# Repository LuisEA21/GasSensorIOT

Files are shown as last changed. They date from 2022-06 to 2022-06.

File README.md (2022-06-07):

# GasSensorIoT

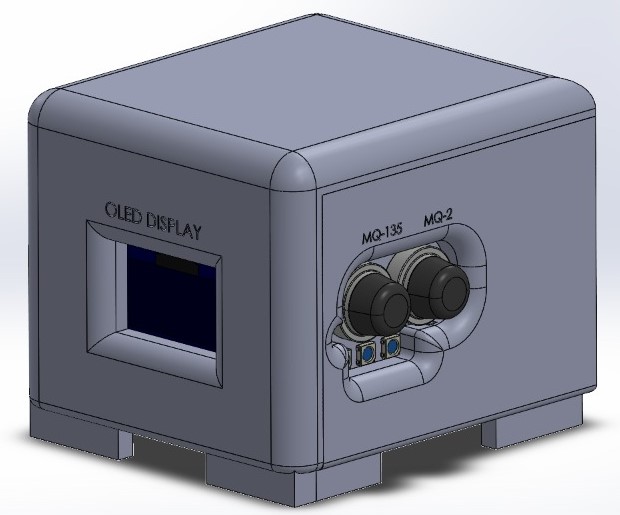
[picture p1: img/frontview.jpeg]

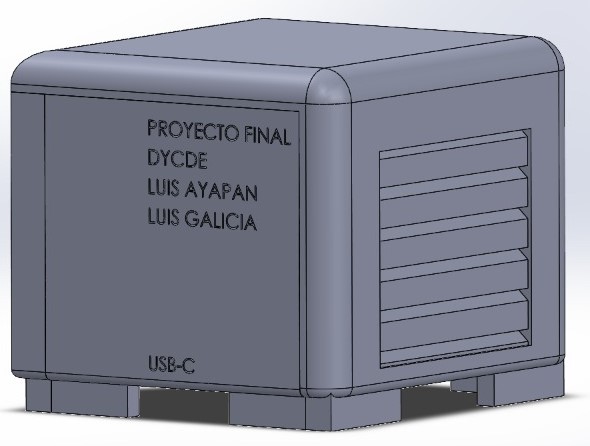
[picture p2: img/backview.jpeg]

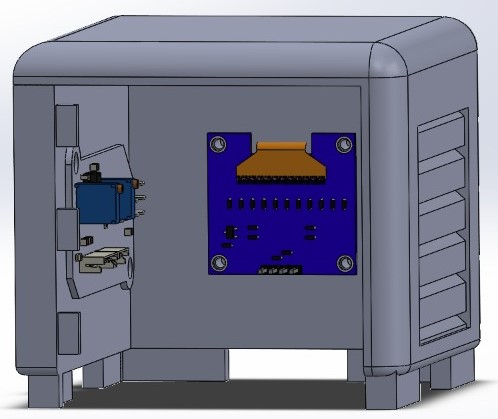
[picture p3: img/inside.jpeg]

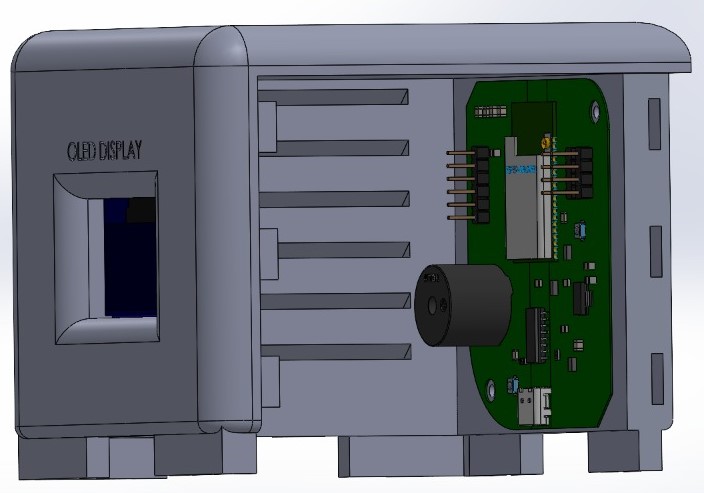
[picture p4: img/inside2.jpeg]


# Descripción del dispositivo

Dispositivo electrónico de IoT para la medición de gases en el ambiente con los sensor MQ-2 y MQ-15. Además contiene un sensor para medir la temperatura y humedad del ambiente. La información de estos sensores es desplegada en tiempo real en una pantalla y son enviados a un servidor en la nube. Este dispositivo se compone de dos tarjetas electrónicas y un chasis impreso en 3D.

# Módulo de sensores

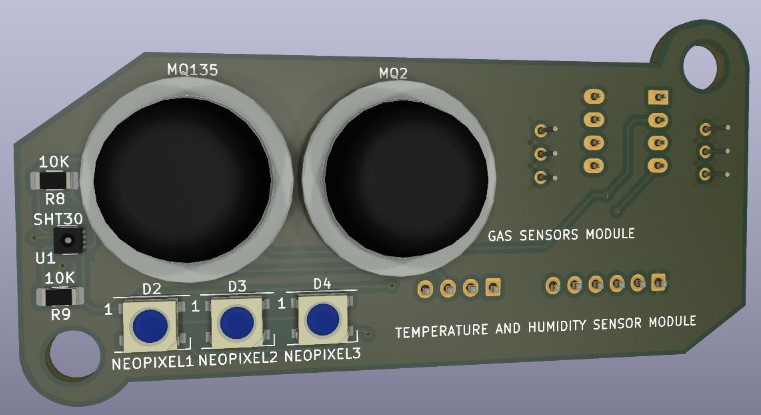
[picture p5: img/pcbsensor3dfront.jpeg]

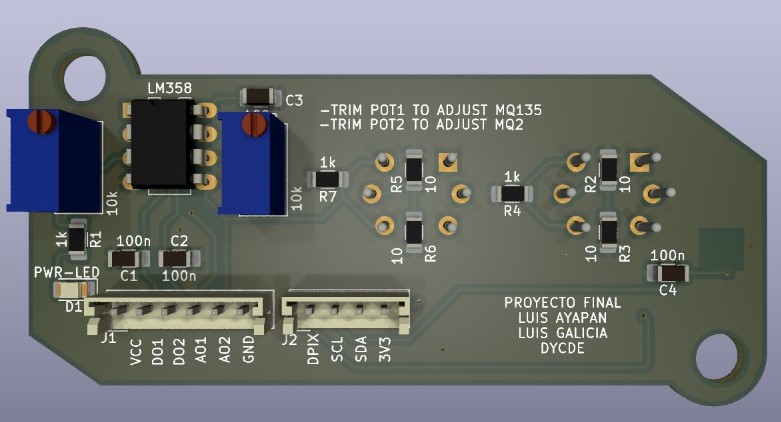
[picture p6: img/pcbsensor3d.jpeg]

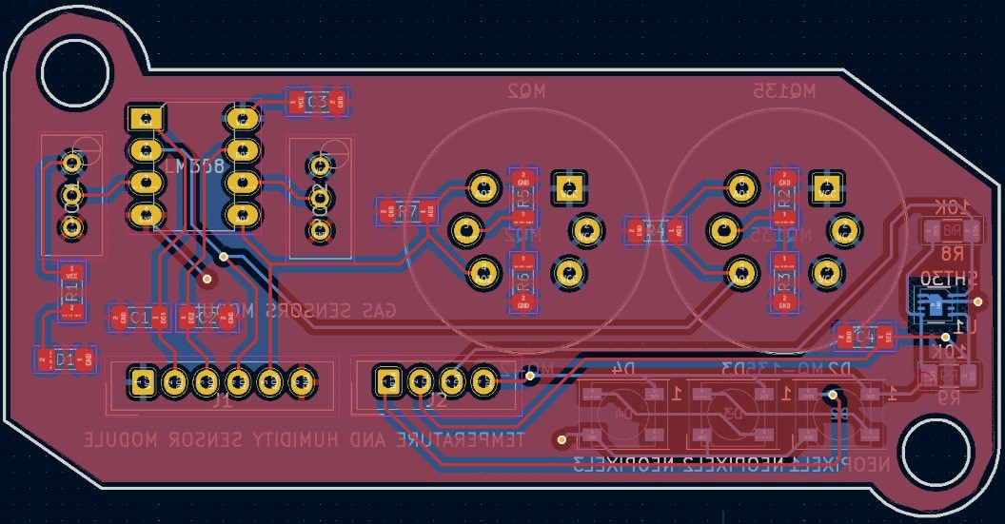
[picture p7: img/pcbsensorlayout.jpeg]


# Tarjeta de control ESP32

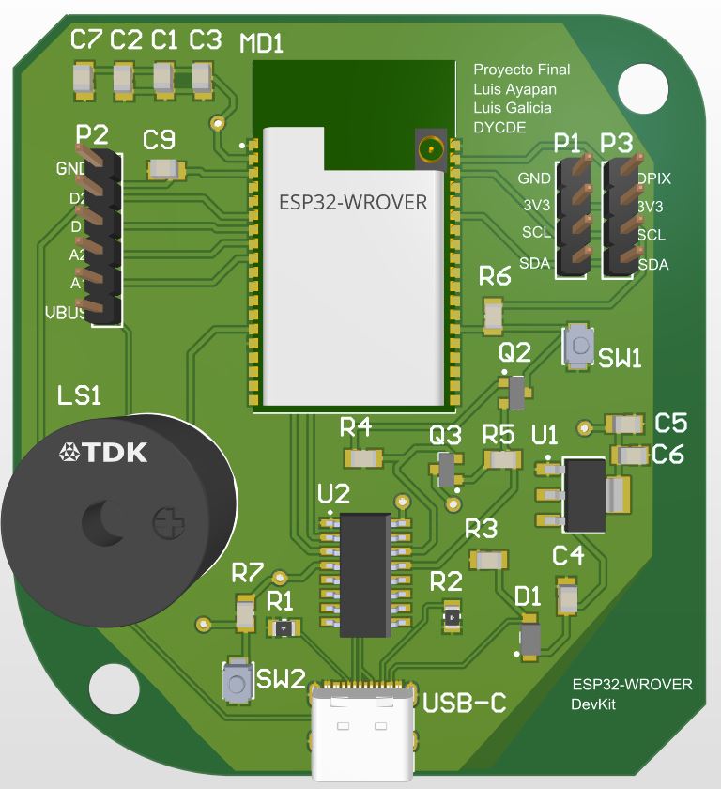
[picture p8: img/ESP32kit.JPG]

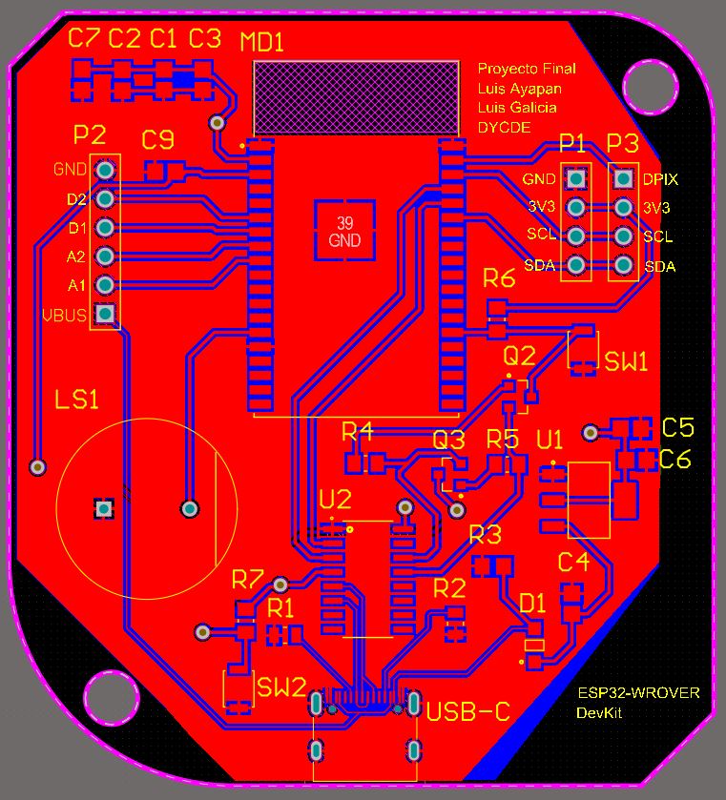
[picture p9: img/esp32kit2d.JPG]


# Mapeo de Pines

## GasSensorIoT V1.0 

### Sensors
Dispositivo | GPIO 
--- | --- 
VCC | VBUS
D2 | 34
D1 | 35
A2 | 32
A1 | 33
GND | Ground

### NeoPixels
Dispositivo | GPIO 
--- | --- 
DataIn | 23
VCC | 3V3
GND | Ground

### Buzzer
Dispositivo | GPIO 
--- | --- 
Buzzer | 12

### Comunicación I2C (Sensor SHT30 y Pantalla)
Dispositivo | GPIO 
--- | --- 
VCC | 3V3
GND | Ground
SCL | 22
SDA | 21

### Comunicación UART
Dispositivo | GPIO 
--- | --- 
VCC | 3V3
GND | Ground
RX | RXD0
TX | TXD0

# Licencia

Hardware License: CERN OHL v1.0

Software License: GPL v3

Documentation License: CC BY 4.0 International

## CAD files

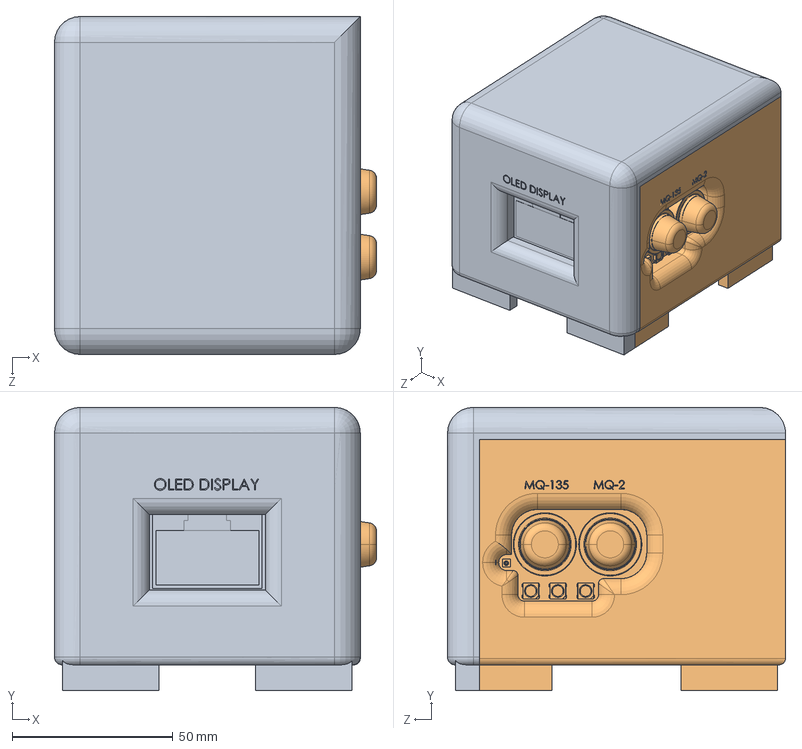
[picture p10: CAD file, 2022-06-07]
3D models/Ensamblaje1.SLDASM
100.0 x 88.0 x 105.0 mm
Oled SH1106
Gas_Sensor_Module
PCBDevkit

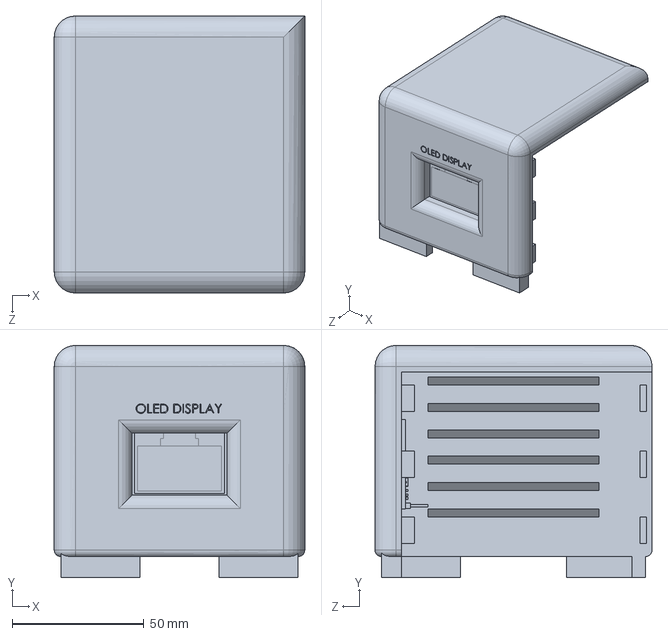
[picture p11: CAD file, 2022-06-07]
3D models/Oled SH1106.SLDPRT
95.0 x 88.0 x 105.0 mm

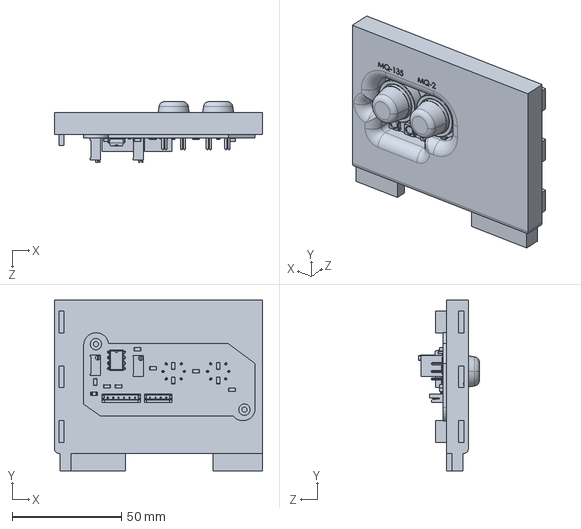
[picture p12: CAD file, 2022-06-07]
3D models/Gas_Sensor_Module.SLDPRT
95.0 x 78.0 x 27.8 mm

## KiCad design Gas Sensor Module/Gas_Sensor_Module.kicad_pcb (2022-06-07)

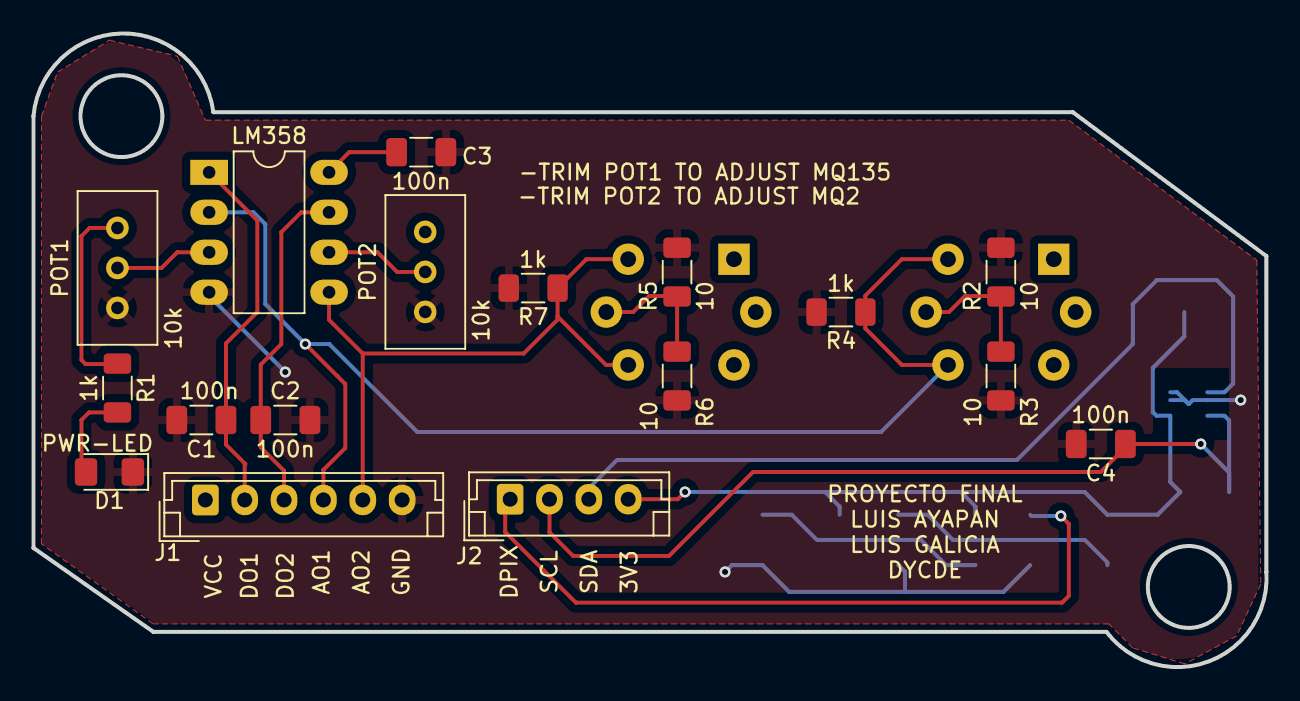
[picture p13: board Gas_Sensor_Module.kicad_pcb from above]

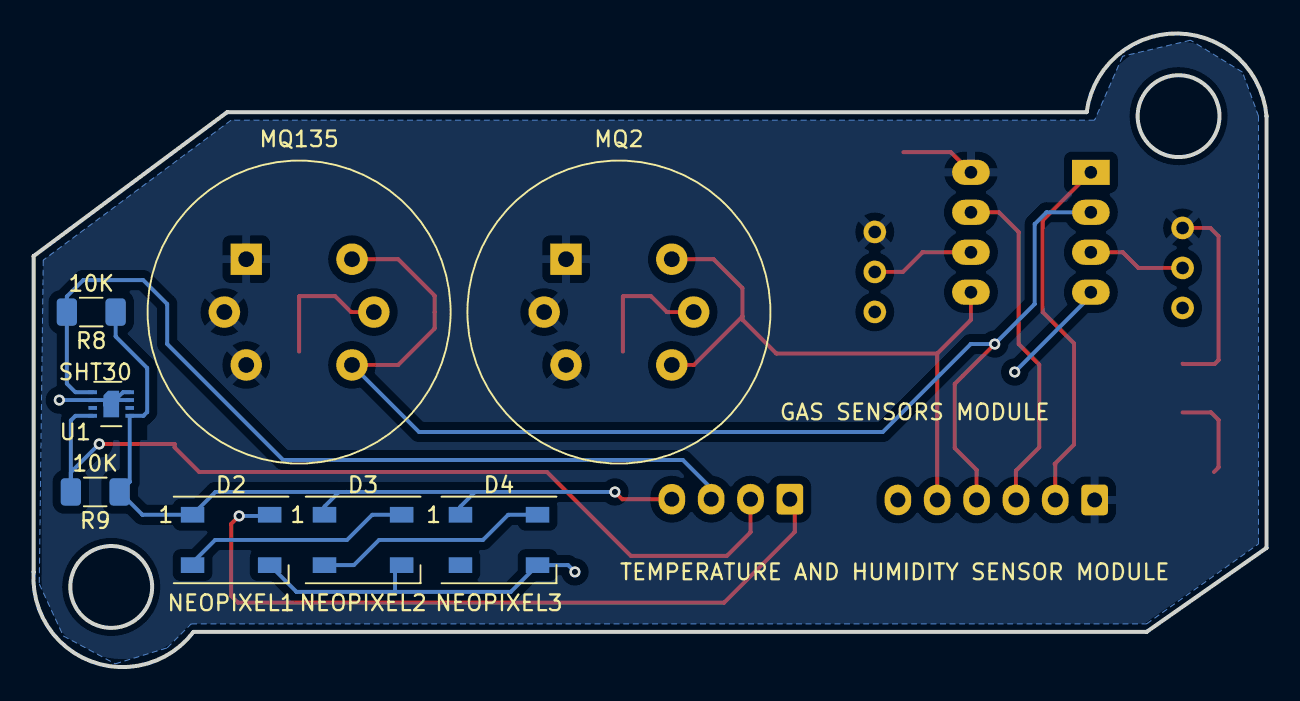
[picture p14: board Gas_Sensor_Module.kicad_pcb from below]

Board: 2 copper layers, 78.3 x 40.3 mm, 25 parts (8 on the bottom side), 17 nets.

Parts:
C1, C2, C3, C4: 100n; C_1206_3216Metric_Pad1.33x1.80mm_HandSolder
D1: PWR-LED; LED_1206_3216Metric_Pad1.42x1.75mm_HandSolder
D2: NEOPIXEL1; LED_WS2812B_PLCC4_5.0x5.0mm_P3.2mm
D3: NEOPIXEL2; LED_WS2812B_PLCC4_5.0x5.0mm_P3.2mm
D4: NEOPIXEL3; LED_WS2812B_PLCC4_5.0x5.0mm_P3.2mm
J1: Conn_01x06_Male; JST_EH_B6B-EH-A_1x06_P2.50mm_Vertical
J2: Conn_01x04_Male; JST_EH_B4B-EH-A_1x04_P2.50mm_Vertical
LM358: LM358; DIP-8_W7.62mm_LongPads
MQ2: MQ-2; MQ-6
MQ135: MQ-135; MQ-6
POT1, POT2: 10k; Potentiometer_Bourns_3296W_Vertical
R1, R4, R7: 1k; R_1206_3216Metric_Pad1.30x1.75mm_HandSolder
R2, R3, R5, R6: 10; R_1206_3216Metric_Pad1.30x1.75mm_HandSolder
R8, R9: 10K; R_1206_3216Metric_Pad1.30x1.75mm_HandSolder
U1: SHT30; Sensirion_DFN-8-1EP_2.5x2.5mm_P0.5mm_EP1.1x1.7mm

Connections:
/3V3: D2.1 (VDD), D3.1 (VDD), D4.1 (VDD), J2.4, R8.1, R9.1, U1.5 (VDD)
/AO1: J1.4, LM358.2 (-), MQ135.4 (A2), MQ135.6 (A1), R4.1
/AO2: J1.5, LM358.5 (+), MQ2.4 (A2), MQ2.6 (A1), R7.1
/DO1: C1.1, J1.2, LM358.1
/DO2: C2.1, J1.3, LM358.7
/DPIX: D2.4 (DIN), J2.1
/SCL: C4.1, J2.2, R9.2, U1.4 (SCL)
/SDA: J2.3, R8.2, U1.1 (SDA)
GND: C1.2, C2.2, C3.2, C4.2, D1.1 (K), D2.3 (VSS), D3.3 (VSS), D4.3 (VSS), J1.6, LM358.4 (V-), POT1.3, POT2.3, R2.2, R3.2, R4.2, R5.2, R6.2, R7.2, U1.2 (ADDR), U1.7 (R), U1.8 (VSS), U1.9 (VSS)
unnamed: D1.2 (A), R1.2
unnamed: D2.2 (DOUT), D3.4 (DIN)
unnamed: D3.2 (DOUT), D4.4 (DIN)
unnamed: LM358.3 (+), POT1.2
unnamed: LM358.6 (-), POT2.2
unnamed: MQ2.5 (VH-), R5.1, R6.1
unnamed: MQ135.5 (VH-), R2.1, R3.1
VCC: C3.1, J1.1, LM358.8 (V+), MQ2.1 (B1), MQ2.2 (VH+), MQ2.3 (B2), MQ135.1 (B1), MQ135.2 (VH+), MQ135.3 (B2), POT1.1, POT2.1, R1.1

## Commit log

2022-06-07 3D models
    [Ensamblaje1.SLDASM, Gas_Sensor_Module.SLDPRT, Oled SH1106.SLDPRT]
2022-06-07 Gas Sensors Module
    [Ensamblaje1.SLDASM, Gas_Sensor_Module.SLDPRT, Gas_Sensor_Module.kicad_pcb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]
2022-06-07 Final 3D designs
    [Ensamblaje1.SLDASM, Gas_Sensor_Module.SLDPRT, Oled SH1106.SLDPRT]
2022-06-07 Final Gas Sensor Module
    [Gas_Sensor_Module-B_Cu.gbr, Gas_Sensor_Module-B_Mask.gbr, Gas_Sensor_Module-B_Paste.gbr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]
2022-06-07 Gas Sensor Module
    [Gas_Sensor_Module-B_Cu.gbr, Gas_Sensor_Module-B_Mask.gbr, Gas_Sensor_Module-B_Paste.gbr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]
2022-06-07 Esp32 files
    [ESP32_DEVKIT.PrjPcb, EsquematicoDevkit.SchDoc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]
